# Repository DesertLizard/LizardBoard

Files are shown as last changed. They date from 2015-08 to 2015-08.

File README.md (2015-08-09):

# Desert Lizard board
Copyright © 2015 Bart Massey

Welcome to the *Desert Lizard*, an open-hardware open-source
beginner e-jewelry and construction tutorial project!

For details and current status, please see our GitHub [wiki](https://github.com/DesertLizard/LizardBoard/wiki).

## License

The hardware design and source code for this project is
available under the MIT License. See the file COPYING in
this distribution for license terms.

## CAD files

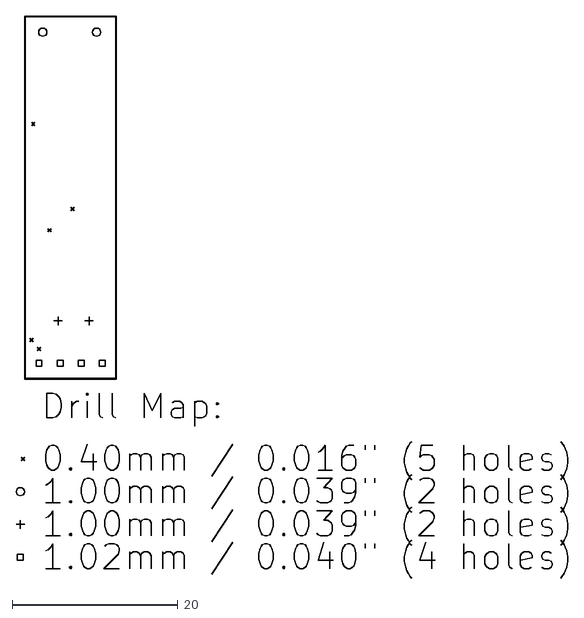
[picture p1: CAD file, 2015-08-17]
plot/lizard-drl_map.dxf
66.6 x 67.8

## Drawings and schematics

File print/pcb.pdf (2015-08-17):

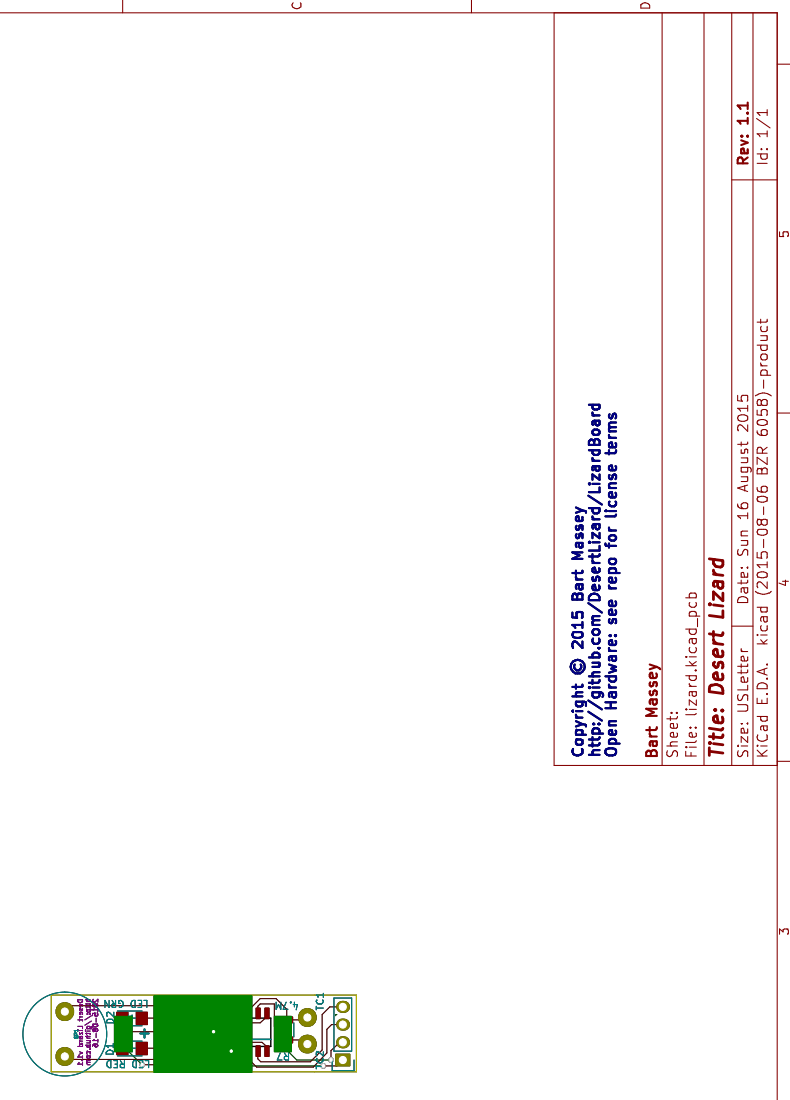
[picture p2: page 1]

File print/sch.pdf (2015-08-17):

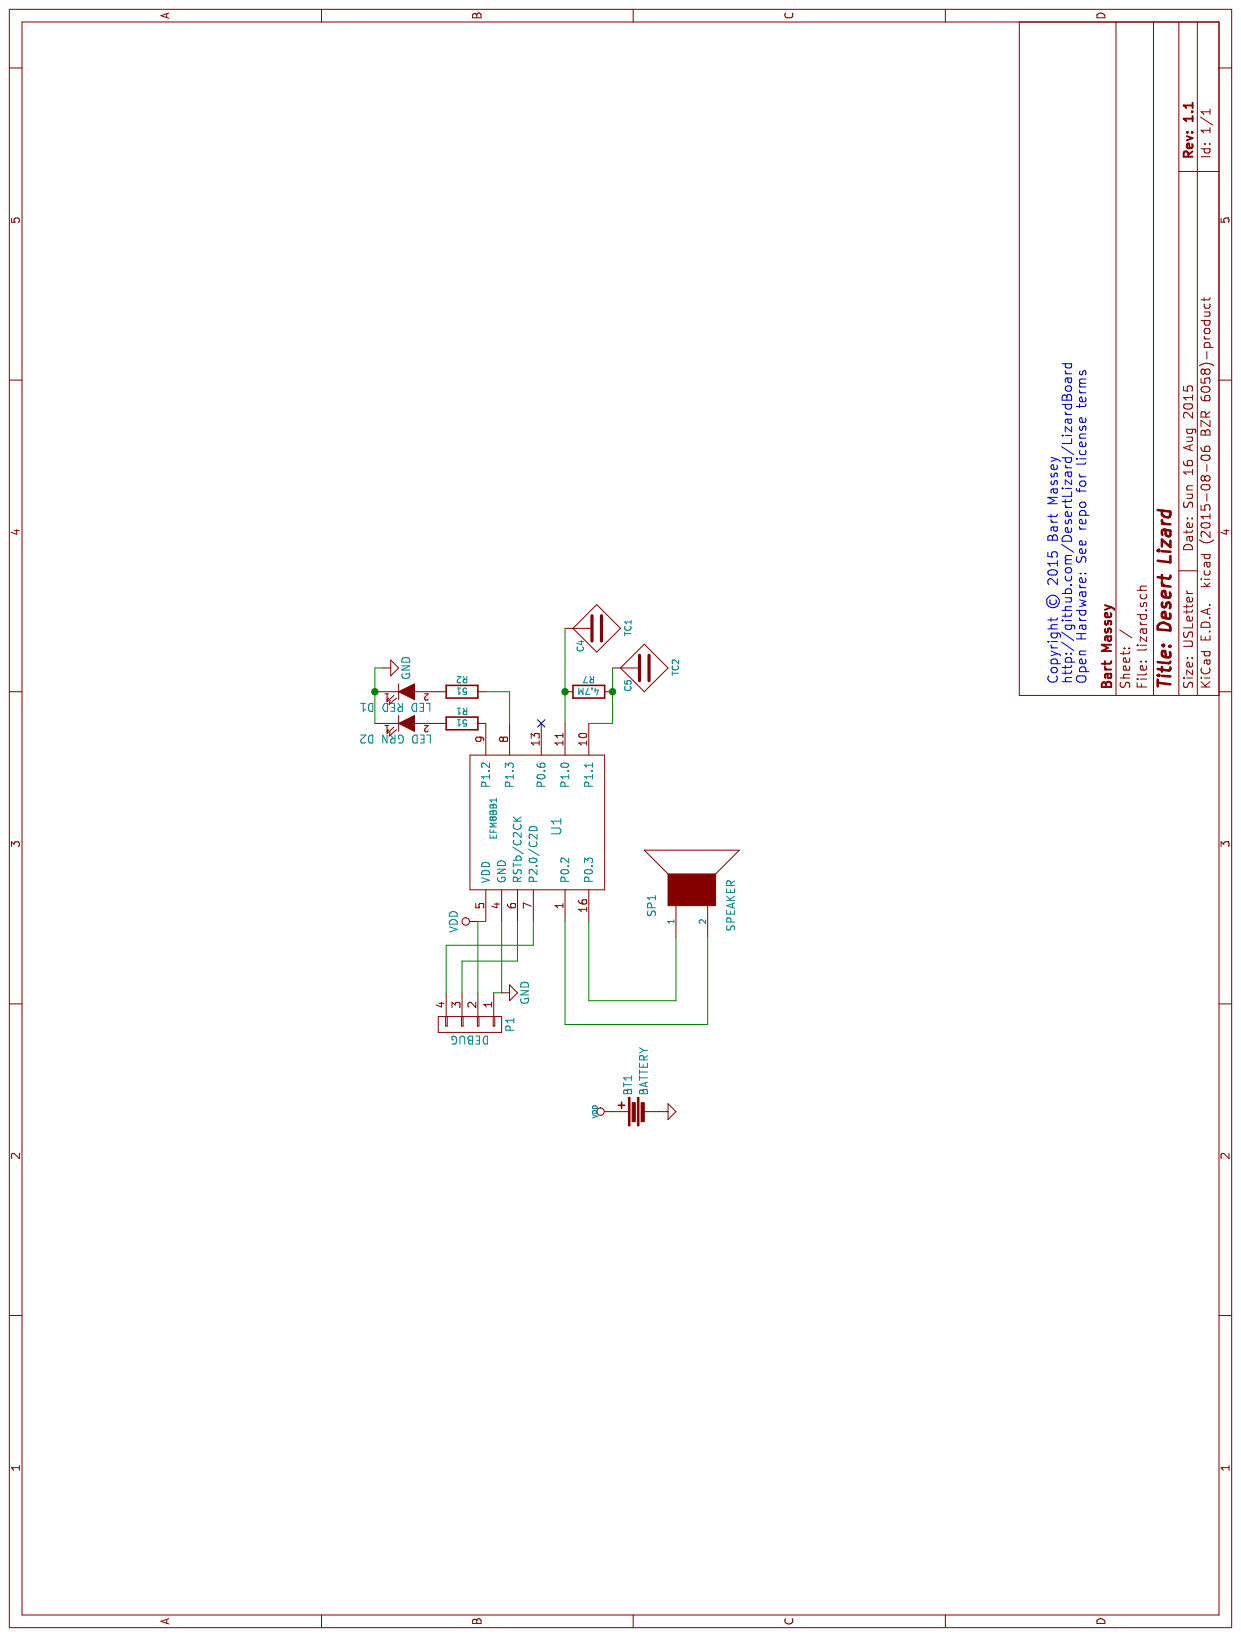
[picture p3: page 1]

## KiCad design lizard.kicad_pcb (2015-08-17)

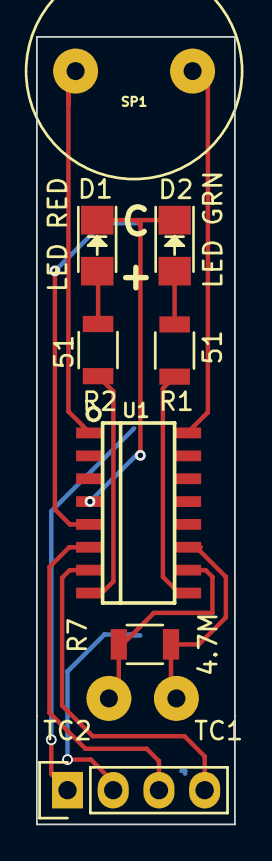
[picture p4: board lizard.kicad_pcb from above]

Board: 2 copper layers, 11.0 x 43.8 mm, 11 parts (1 on the bottom side), 12 nets.

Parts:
BT1: BATTERY; linx-bat-hld-001
C4: TC1; SolderWirePad_single_1mmDrill
C5: TC2; SolderWirePad_single_1mmDrill
D1: LED RED; LED-1206
D2: LED GRN; LED-1206
P1: DEBUG; Pin_Header_Straight_1x04
R1, R2: 51; R_1206
R7: 4.7M; R_1206
SP1: SPEAKER; PUI-AT-1224-TWT-5V-2-R
U1: EFM8BB1; soic16

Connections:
GND: BT1.2, D1.1, D2.1, P1.1, U1.4
unnamed: C4.1, R7.1, U1.11
unnamed: C5.1, R7.2, U1.10
unnamed: D1.2, R2.1
unnamed: D2.2, R1.1
unnamed: P1.3, U1.6
unnamed: P1.4, U1.7
unnamed: R1.2, U1.9
unnamed: R2.2, U1.8
unnamed: SP1.1, U1.16
unnamed: SP1.2, U1.1
VDD: BT1.1, P1.2, U1.5

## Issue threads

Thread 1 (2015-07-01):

Board back text is tiny

BartMassey, 2015-07-01:
The board back text is at least a factor of two too small.

BartMassey, 2015-07-04:
Fixed.

Closed 2015-07-04.

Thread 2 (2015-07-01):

Wrong LEDs on board

BartMassey, 2015-07-01:
Board wants to have the 1206 LEDs rather than the 0805 LEDs.

BartMassey, 2015-08-10:
1206 LEDs are now on board.

Closed 2015-08-10.

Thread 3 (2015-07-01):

Speaker pads on board are screwed up

BartMassey, 2015-07-01:
The speaker pads on the board are probably too small, and definitely have solder mask where they shouldn't.

BartMassey, 2015-07-01:
Speaker holes are about 0.6mm.

BartMassey, 2015-07-04:
Unfortunately speaker pins (contrary to drawings) turned out to be square and 0.6mm on a side. Fixed.

Closed 2015-07-04.

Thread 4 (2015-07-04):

Need clear anode/cathode marking for diode silk

BartMassey, 2015-07-04:
As it stands, it's not obvious from the board which way round it goes.

BartMassey, 2015-08-10:
Added + at anode and C at cathode. There's also a diode symbol on the silk. This seems like enough.

Closed 2015-08-10.

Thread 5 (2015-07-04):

Move battery holder (and speaker?) to back; make holder hand-solderable

BartMassey, 2015-07-04:
This will dramatically cut board size. Is it OK to have the speaker facing the wrong way? I think it wants to be on the other side from the battery and the same side as the LEDs, sadly.

BartMassey, 2015-07-04:
To make the holder hand-solderable, the pads just need to be extended a bit to be externally accessible.

BartMassey, 2015-08-10:
Switched holders so hand-solderable will be different. Moved battery holder to back. Speaker stays in front.

BartMassey, 2015-09-12:
Seems to work now.

Closed 2015-09-12.

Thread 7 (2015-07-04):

External voltage ref for TC comparator needs to move or disappear

BartMassey, 2015-07-04:
Sadly, the pins that can be attached to each input of the external comparator are different for each package the EFM8BB1 comes in. For the SOIC-16 used here, P0.6 is on the same side of the comparator as P1.0 and P1.1. Unfortunately, I used P0.6 for the external voltage ref and P1.0 and P1.1 as capacitive touch inputs.  If it turns out we need that reference (unlikely), I'll have to move it, probably to P0.5.

BartMassey, 2015-07-04:
Was misreading the documentation. CMP1 should work just fine. Pure luck, really.

Closed 2015-07-04.

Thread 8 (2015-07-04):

Add reset button, power switch to debugging prototype

BartMassey, 2015-07-04:
If there's another debugging board turn, add a power switch and a reset button.

BartMassey, 2015-07-10:
Won't be doing another run of prototype boards, so meh.

Closed 2015-07-10.

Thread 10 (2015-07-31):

Evaluate which components can be removed in final version.

BartMassey, 2015-07-31:
Short or open components that are likely optional:

* Remove power supply filtering
* Short speaker decoupling cap
* Maybe open Touch Cap drain resistor
* (Maybe) short LED current limit resistors

Based on results of these experiments, modify final board design.

BartMassey, 2015-08-07:
Evie pulled all the caps. The board still works fine. I'm not sure what else we are doing yet.

BartMassey, 2015-08-10:
Looks like we pretty much have the final parts package.

* As noted, all the caps are gone.
* The pullup resistor on reset that was inadvertently left out in layout will not be replaced unless needed. * The voltage divider reference for the TC was not needed and is gone.
* We've gone from two drain resistors for the TC to one.

That leaves us with three passives, which is not bad.

Closed 2015-08-10.

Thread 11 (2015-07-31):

Power management

BartMassey, 2015-07-31:
Figure out how to halt the CPU. Then figure out how to get one of the timer-counters to wake the CPU up periodically to check on stuff.

BartMassey, 2015-08-10:
Moved issue to software.

Closed 2015-08-10.

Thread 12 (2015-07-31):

Layout and cut prototype production board

BartMassey, 2015-07-31:
Get the prototype production board layed out and cut at LID.

BartMassey, 2015-08-07:
All layed out and ready to cut. There's some question about form for the debug connector, but for now we'll go with the USB Debug Adapter plug.

BartMassey, 2015-09-12:
Done. Also production board.

Closed 2015-09-12.

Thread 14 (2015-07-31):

Build programming jig

BartMassey, 2015-07-31:
What the title says. Cut board at LID.

BartMassey, 2015-09-12:
Board is assembled, but does not work.

BartMassey, 2017-01-10:
Giving up on the terrible cheap ZIF socket. We'll just pre-build the lizards and program them with more conventional pins.

Closed 2017-01-10.

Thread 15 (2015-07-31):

Get play-doh setup for cases together

BartMassey, 2015-07-31:
* Find play-doh recipe
* Acquire play-doh ingredients
* Acquire paints for outside
* Verify low-temperature curing *or*
* Acquire propane torch and verify curing

* **Optional:** 3D print case mold for the non-creative.

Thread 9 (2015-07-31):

Get basic capacitive touch working

BartMassey, 2015-07-31:
* Solder wires to TC pads
* Evaluate Silicon Labs TC library
* Demo simple capacitance measurements
* Try to do without external voltage divider

BartMassey, 2015-08-10:
Evie did this!

Closed 2015-08-10.

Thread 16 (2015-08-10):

Figure out mounting plan for board.

BartMassey, 2015-08-10:
With the new side-loading battery holder and no space on the board for mounting holes, figure out how we're going to mount the board securely in the lizard.

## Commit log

2015-06-12 desert lizard board in KiCad
    [lizard-B_Cu.gbr, lizard-B_Mask.gbr, lizard-B_Paste.gbr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]
2015-06-13 fixed bugs; added plots
    [lizard-B_Cu.gbr, lizard-B_Mask.gbr, lizard-B_Paste.gbr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]
2015-06-13 added KiCAD section to docs
2015-06-15 fixed buglets in pcb
    [lizard-B_Cu.gbr, lizard-B_Mask.gbr, lizard-B_Paste.gbr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]
2015-06-21 updated to use extra board size; passed last check
    [lizard-B_Cu.gbr, lizard-B_Mask.gbr, lizard-B_SilkS.gbr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]
2015-06-21 fixed bugs noticed during next OSHPark upload
    [lizard-B_Cu.gbr, lizard-B_Mask.gbr, lizard-B_SilkS.gbr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]
2015-07-02 increased speaker pin hole size; increased back text size
    [lizard-B_Cu.gbr, lizard-B_Mask.gbr, lizard-B_SilkS.gbr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]
2015-07-04 made improvements to front silk
    [lizard-B_Cu.gbr, lizard-B_Mask.gbr, lizard-B_SilkS.gbr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]
2015-08-06 finished cheesed redo of schematic and layout for v1.0 production board
    This pass is the first at something that will eventually
    look pretty much like the production PCB. Changes include
    removing all the capacitors as gratuitous, removing the
    gratuitous touchpad resistor, moving the battery to the back
    and enlarging the tabs for hand soldering, moving to the new
    LEDs, and changing to the USB Debug Device compatible debug
    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
    [lizard-B_Cu.gbr, lizard-B_Mask.gbr, lizard-B_SilkS.gbr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]
2015-08-06 fixed LED resistor values; fixed silk values; misc fixes
    [lizard-B_Cu.gbr, lizard-B_Mask.gbr, lizard-B_SilkS.gbr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]
2015-08-08 fixed LED resistor values; removed voltage divider; cleaned up layout
    [lizard-B_Cu.gbr, lizard-B_Mask.gbr, lizard-B_SilkS.gbr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]
2015-08-10 added + and C for diodes
    [lizard.kicad_pcb]
2015-08-10 moved some more stuff on silk; updated art
    [lizard-B_Cu.gbr, lizard-B_Mask.gbr, lizard-B_SilkS.gbr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]
2015-08-12 did relayout for new battery holder; shrunk board dramatically; simplified layout
    [lizard-B_Cu.gbr, lizard-B_Mask.gbr, lizard-B_SilkS.gbr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]
2015-08-12 made minor tweaks to layout pre-cut
    [lizard-B_Cu.gbr, lizard-B_Mask.gbr, lizard-B_SilkS.gbr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]
2015-08-17 prepped for OSH Park; need to fix battery ground
    [lizard-B_Cu.gbr, lizard-B_Mask.gbr, lizard-B_SilkS.gbr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]
2015-08-17 modified battery ground to fit board
    [lizard-B_Cu.gbr, lizard-B_Mask.gbr, lizard-B_SilkS.gbr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]
2015-08-17 replaced battery ground fill covered by mask with big rectangular pad
    [lizard-B_Cu.gbr, lizard-B_Mask.gbr, lizard-B_SilkS.gbr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]

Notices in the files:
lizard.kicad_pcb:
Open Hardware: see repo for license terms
